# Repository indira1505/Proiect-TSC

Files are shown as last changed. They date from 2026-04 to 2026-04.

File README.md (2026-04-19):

INK TIME SMARTWATCH

1. DIAGRAMA COMPONENTE
    Acesta este un proiect de ceas inteligent bazat pe arhitectura nRF52840, echipat cu un ecran
e-Paper pentru consum redus și un sistem de alertă haptică.

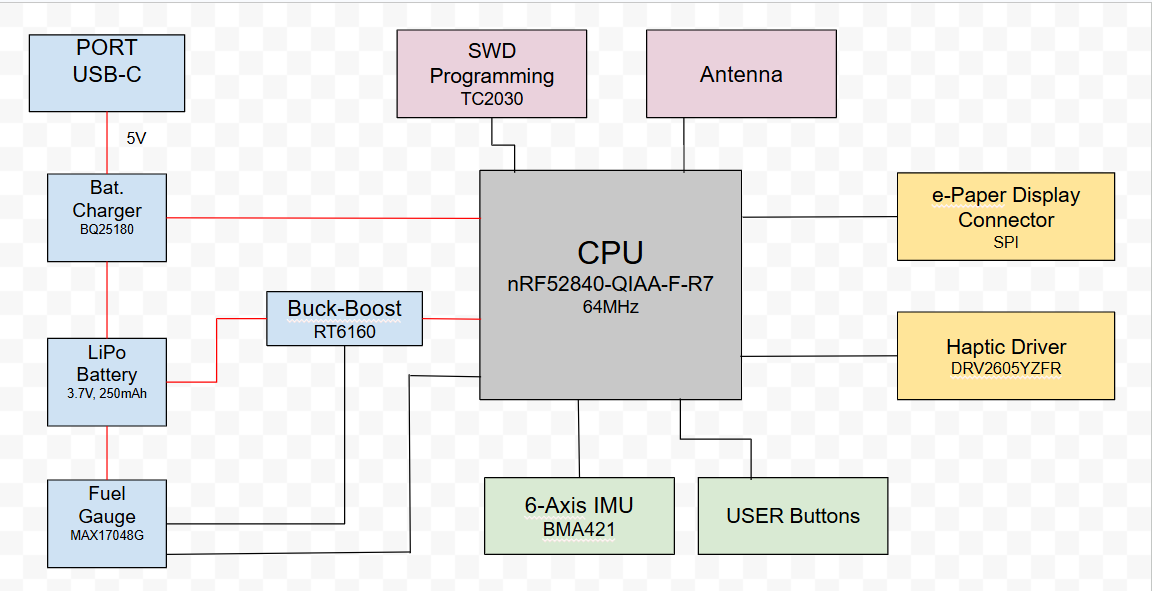
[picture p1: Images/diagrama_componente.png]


2. Bill Of Materials

| Qty | Value | Device | Package | Parts | Description | ARROW_PART_NUMBER | ARROW_PRICE-STOCK | AVAILABILITY | CHECK_PRICES | COPYRIGHT | DESCRIPTION | HEIGHT | JLCPCB | MANUFACTURER_NAME | MANUFACTURER_PART_NUMBER | MF | MFR_NAME | MOUSER_PART_NUMBER | MOUSER_PRICE-STOCK | MP | PACKAGE | POPULARITY | PRICE | PROD_ID | PURCHASE-URL | SNAPEDA_LINK | TP_SIGNAL_NAME | U1 | VALUE |
|-----|---|---|---|---|---|---|---|---|---|---|---|---|---|---|---|---|---|---|---|---|---|---|---|---|---|---|---|---|---|
| 1 | RT6160AWSC | RT6160AWSC_RT6160AWSC | RT6160AWSC_BGA15C40P3X5_140X230X60 | IC9 | Buck-Boost Regulator Positive Output Step-Up/Step-Down I2C DC-DC Controller IC 15-WL-CSP (BSC) (1.4x2.3) | | | | | | Buck-Boost Regulator Positive Output Step-Up/Step-Down I2C DC-DC Controller IC 15-WL-CSP (BSC) (1.4x2.3) | 0.6mm | | RICHTEK | RT6160AWSC | | | 835-RT6160AWSC | https://www.mouser.co.uk/ProductDetail/Richtek/RT6160AWSC?qs=amGC7iS6iy%2FLd9PSoixZXQ%3D%3D | | | | | | | | | | |
| 1 | SI1308EDL-T1-GE3 | ESP32_C6_LIBRARY_6_SI1308EDL-T1-GE3 | ESP32_C6_LIBRARY_6_SOT65P210X110-3N | Q3 | MOSFET N-Ch 30V 1.5A TrenchFET SC70 Vishay Si1308EDL-T1-GE3 N-channel MOSFET Transistor, 1.5 A, 30 V, 3-Pin SC-70 | | | In Stock | https://www.snapeda.com/parts/SI1308EDL-T1-GE3/Vishay+Siliconix/view-part/?ref=eda | | Si1308EDL-T1-GE3 N-channel MOSFET Transistor | 1.5 A | 30 V | 3-Pin SC-70 | Siliconix / Vishay SI1308EDL-T1-GE3 | | | | | Vishay Siliconix | | | | SI1308EDL-T1-GE3 | SOT-323 Vishay Semiconductor | | None | | https://www.snapeda.com/api/url_track_click_mouser/?unipart_id=274603&manufacturer=Vishay Siliconix&part_name=SI1308EDL-T1-GE3&search_term=None | https://www.snapeda.com/parts/SI1308EDL-T1-GE3/Vishay+Siliconix/view-part/?ref=snap |
| 1 | TC2030-IDC | TC2030-IDC_TC2030-IDC | TC2030-IDC_TC2030IDC | J2 | CABLE ADAPTER 6 POS | | | | | | CABLE ADAPTER 6 POS | 19mm | | Tag Connect | TC2030-IDC | | | | | | | | | | | | | | |
| 1 | USBLC6-2SC6Y | ESP32_C6_LIBRARY_3_USBLC6-2SC6Y | ESP32_C6_LIBRARY_3_SOT95P280X145-6N | D3 | Low Cap. ESD Protection Auto SOT-23-6 STMicroelectronics USBLC6-2SC6Y, Dual Uni-Directional TVS Diode Array, 6-Pin SOT-23 | | | In Stock | https://www.snapeda.com/parts/USBLC6-2SC6Y/STMicroelectronics/view-part/?ref=eda | | 17V Clamp 5A (8/20µs) Ipp Tvs Diode Surface Mount SOT-23-6 | | | | | STMicroelectronics | | | | USBLC6-2SC6Y | SOT-23-6 STMicroelectronics | | None | | | https://www.snapeda.com/parts/USBLC6-2SC6Y/STMicroelectronics/view-part/?ref=snap | | | |
| 1 | 0.1uF/50V | NORDIC_NRF_3_CAPACITOR_0201_L | NORDIC_NRF_3_RESC0201_L | EPD_C5 | Generic chip capacitor | | | | | | | | | | | | | | | | | | | | | | | | |
| 1 | 0.47 | CPF0201D7K68C1_CPF0201D7K68C1 | CPF0201D7K68C1_0201 | R1_EP_DR | 7.68k 0201 Thin Film Surface Mount Fixed Resistor +/-0.5% 0.031W CPF0201D7K68C1 | | | | | | | | | | | | | | | | | | | | | | | | |
| 1 | 1.0µF | NORDIC_NRF_3_CAPACITOR_0201_L | NORDIC_NRF_3_RESC0201_L | C15 | Generic chip capacitor | | | | | | | | | | | | | | | | | | | | | | | | |
| 5 | 100nF | NORDIC_NRF_3_CAPACITOR_0201_L | NORDIC_NRF_3_RESC0201_L | C5, C7, C8, C12, C19 | Generic chip capacitor | | | | | | | | | | | | | | | | | | | | | | | | |
| 1 | 100pF | NORDIC_NRF_3_CAPACITOR_0201_L | NORDIC_NRF_3_RESC0201_L | C11 | Generic chip capacitor | | | | | | | | | | | | | | | | | | | | | | | | |
| 4 | 0.1uF | GRM011R60J152KE01L_2_GRM011R60J152KE01L | GRM011R60J152KE01L_2_CAPC0201X13N | C23, C27, C34, C42 | Check availability | | | In Stock | https://www.snapeda.com/parts/GRM011R60J152KE01L/Murata/view-part/?ref=eda | | SMD Capacitor X5R(EIA) with Capacitance: 1500pF Tol. 10%. Rated Voltage: 6.3Vdc | | | | | Murata | | | | GRM011R60J152KE01L | 0201 Murata | | None | | | https://www.snapeda.com/parts/GRM011R60J152KE01L/Murata/view-part/?ref=snap | | | |
| 3 | 10K | CPF0201D7K68C1_CPF0201D7K68C1 | CPF0201D7K68C1_0201 | R2_EP_DR, R9, R_PWR_EPD | 7.68k 0201 Thin Film Surface Mount Fixed Resistor +/-0.5% 0.031W CPF0201D7K68C1 | | | | | | | | | | | | | | | | | | | | | | | | |
| 3 | 10K | ERA-1AEB3401C_CPF0201D7K68C1 | ERA-1AEB3401C_0201 | R5, R7, R8 | 7.68k 0201 Thin Film Surface Mount Fixed Resistor +/-0.5% 0.031W CPF0201D7K68C1 | | | | | | | | | | | | | | | | | | | | | | | | |
| 1 | 10uF | NORDIC_NRF_3_CAPACITOR_0201_L | NORDIC_NRF_3_RESC0201_L | C1-EP-DR | Generic chip capacitor | | | | | | | | | | | | | | | | | | | | | | | | |
| 2 | 10uF | PERFECT_0402_CAP_0402 | PERFECT_0402_0402 | C24, C39 | 0402 (1005 Metric) | | | | | | | | | | | | | | | | | | | | | | | | |
| 1 | | ESP32_C6_LIBRARY_7_JUMPER_SJ | ESP32_C6_LIBRARY_7_JUMPER_SJ | SJ1 | SMD solder JUMPER | | | | | | | | | | | | | | | | | 3 | | | | | | | |
| 3 | 0 | CPF0201D7K68C1_CPF0201D7K68C1 | CPF0201D7K68C1_0201 | R2, R3, R4 | 7.68k 0201 Thin Film Surface Mount Fixed Resistor +/-0.5% 0.031W CPF0201D7K68C1 | | | | | | | | | | | | | | | | | | | | | | | | |
| 1 | 10µH | NORDIC_NRF_2_INDUCTOR_0402_L | NORDIC_NRF_2_RESC0402_L | L2 | Generic chip inductor | | | | | | | | | | | | | | | | | | | | | | | | |
| 4 | 12pF | NORDIC_NRF_3_CAPACITOR_0201_L | NORDIC_NRF_3_RESC0201_L | C1, C2, C17, C18 | Generic chip capacitor | | | | | | | | | | | | | | | | | | | | | | | | |
| 1 | 15nH | NORDIC_NRF_2_INDUCTOR_0402_L | NORDIC_NRF_2_RESC0402_L | L3 | Generic chip inductor | | | | | | | | | | | | | | | | | | | | | | | | |
| 2 | 1pF | NORDIC_NRF_3_CAPACITOR_0201_L | NORDIC_NRF_3_RESC0201_L | C3, C4 | Generic chip capacitor | | | | | | | | | | | | | | | | | | | | | | | | |
| 6 | 1uF | GRM011R60J152KE01L_2_GRM011R60J152KE01L | GRM011R60J152KE01L_2_CAPC0201X13N | C29, C30, C31, C32, C37, C38 | Check availability | | | In Stock | https://www.snapeda.com/parts/GRM011R60J152KE01L/Murata/view-part/?ref=eda | | SMD Capacitor X5R(EIA) with Capacitance: 1500pF Tol. 10%. Rated Voltage: 6.3Vdc | | | | | Murata | | | | GRM011R60J152KE01L | 0201 Murata | | None | | | https://www.snapeda.com/parts/GRM011R60J152KE01L/Murata/view-part/?ref=snap | | | |
| 9 | 1uF/50V | NORDIC_NRF_3_CAPACITOR_0201_L | NORDIC_NRF_3_RESC0201_L | EPD_C1, EPD_C2, EPD_C6, EPD_C7, EPD_C8, EPD_C9, EPD_C10, EPD_C11, EPD_C12 | Generic chip capacitor | | | | | | | | | | | | | | | | | | | | | | | | |
| 1 | 2.2 | CPF0201D7K68C1_CPF0201D7K68C1 | CPF0201D7K68C1_0201 | R_TYPE_SEL | 7.68k 0201 Thin Film Surface Mount Fixed Resistor +/-0.5% 0.031W CPF0201D7K68C1 | | | | | | | | | | | | | | | | | | | | | | | | |
| 3 | 2025-10-22_07-23-44_LIBRARY_EVP-AKE31A | 2025-10-22_07-23-44_LIBRARY_EVP-AKE31A | 2025-10-22_07-23-44_LIBRARY_SW_EVP-AKE31A_PAN | SW_DN, SW_ENT, SW_UP | | | | | | | | | | | | | | | | | | | | | | | | | |
| 1 | 20V/4.2A/52mΩ/1.4W | ESP32_C6_LIBRARY_4_ESP32_WROVER_SPARKFUN-DISCRETESEMI_MOSFET_PCH-DMG2305UX-7 | ESP32_C6_LIBRARY_4_ESP32_C6_LIBRARY_4_ESP32_C6_LIBRARY_4_ESP32_C6_LIBRARY_4_ESP32_WROVER_SPARKFUN-DISCRETESEMI_SOT23-3 | Q1 | P-channel MOSFETs | | | | | | | | | | | | | | | | | | | TRAN-14388 | | | | | 20V/4.2A/52mΩ/1.4W |
| 2 | 22uF | PERFECT_0402_CAP_0402 | PERFECT_0402_0402 | C25, C33 | 0402 (1005 Metric) | | | | | | | | | | | | | | | | | | | | | | | | |
| 1 | 2450AT18B100E | 2450AT18B100E_2450AT18B100E | 2450AT18B100E_ANTC3216X140N | ANT1 | Antennas 2.45GHz ANTENNA | 2450AT18B100E | https://www.arrow.com/en/products/2450at18b100e/johanson-dielectrics?utm_currency=USD&region=nac | | | | Antennas 2.45GHz ANTENNA | 1.4mm | | JOHANSON TECHNOLOGY | 2450AT18B100E | | | 609-2450AT18B100E  | https://www.mouser.co.uk/ProductDetail/Johanson-Technology/2450AT18B100E?qs=yCnrNFeXz%252Bh5MFsFIXGZGA%3D%3D | | | | | | | | | | |
| 1 | 3.9nH | NORDIC_NRF_2_INDUCTOR_0402_L | NORDIC_NRF_2_RESC0402_L | L1 | Generic chip inductor | | | | | | | | | | | | | | | | | | | | | | | | |
| 1 | 32.768kHz | NORDIC_NRF_1_XTAL_32KHZ | NORDIC_NRF_1_XTAL_3215_N | X2 | | | | | | | | | | | | | | | | | | | | | | | | | |
| 1 | 32MHz | NORDIC_NRF_XTAL_32MHZ | NORDIC_NRF_BT-XTAL_2016_N | X1 | | | | | | | | | | | | | | | | | | | | | | | | | |
| 2 | 3K3 | CPF0201D7K68C1_CPF0201D7K68C1 | CPF0201D7K68C1_0201 | R17, R18 | 7.68k 0201 Thin Film Surface Mount Fixed Resistor +/-0.5% 0.031W CPF0201D7K68C1 | | | | | | | | | | | | | | | | | | | | | | | | |
| 1 | 4.7uF | NORDIC_NRF_3_CAPACITOR_0201_L | NORDIC_NRF_3_RESC0201_L | C43 | Generic chip capacitor | | | | | | | | | | | | | | | | | | | | | | | | |
| 1 | 4.7uF/25V | NORDIC_NRF_3_CAPACITOR_0201_L | NORDIC_NRF_3_RESC0201_L | C2-EP-DR | Generic chip capacitor | | | | | | | | | | | | | | | | | | | | | | | | |
| 4 | 4.7µF | NORDIC_NRF_3_CAPACITOR_0201_L | NORDIC_NRF_3_RESC0201_L | C6, C14, C20, C21 | Generic chip capacitor | | | | | | | | | | | | | | | | | | | | | | | | |
| 1 | 47nF | NORDIC_NRF_3_CAPACITOR_0201_L | NORDIC_NRF_3_RESC0201_L | C16 | Generic chip capacitor | | | | | | | | | | | | | | | | | | | | | | | | |
| 1 | 503480-2400 | 503480-2400_503480-2400 | 503480-2400_5034802400 | J1 | FFC & FPC Connectors 0.5mm FPC RA SMT Dual Contact 24Ckt | | | | | | FFC & FPC Connectors 0.5mm FPC RA SMT Dual Contact 24Ckt | 1.87mm | | Molex | 503480-2400 | | | 538-503480-2400 | https://www.mouser.co.uk/ProductDetail/Molex/503480-2400?qs=OAhjpuo3Vu7efIoxFh9AOw%3D%3D | | | | | | | | | | |
| 2 | 5K1 | CPF0201D7K68C1_CPF0201D7K68C1 | CPF0201D7K68C1_0201 | R1_USB, R2_USB | 7.68k 0201 Thin Film Surface Mount Fixed Resistor +/-0.5% 0.031W CPF0201D7K68C1 | | | | | | | | | | | | | | | | | | | | | | | | |
| 1 | 68uH | ESP32_C6_LIBRARY_2_744043680IND_4828-WE-TPC_WRE | ESP32_C6_LIBRARY_2_IND_4828-WE-TPC_WRE | L5 | | | | | | Copyright (C) 2024 Ultra Librarian. All rights reserved. | | | | | 744043680 | | Wurth Electronics | | | | | | | | | | | | |
| 1 | 820pF N.C. | NORDIC_NRF_3_CAPACITOR_0201_L | NORDIC_NRF_3_RESC0201_L | C9 | Generic chip capacitor | | | | | | | | | | | | | | | | | | | | | | | | |
| 1 | BMA421 | BMA423_BMA423 | BMA423_BMA423 | IC3 | Accelerometers Triaxial low-g 12bit Acceleration Sensor | BMA423 | https://www.arrow.com/en/products/bma423/bosch | | | | Accelerometers Triaxial low-g 12bit Acceleration Sensor | 1mm | | BOSCH | BMA423 | | | 262-BMA423 | https://www.mouser.co.uk/ProductDetail/Bosch-Sensortec/BMA423?qs=HXFqYaX1Q2xC%252BSgeGoX3mg%3D%3D | | | | | | | | | | |
| 1 | BQ25180YBGR | BQ25180YBGR_BQ25180YBGR | BQ25180YBGR_BGA8C40P2X4_100X155X50 | IC1 | Charger IC Lithium Ion/Polymer, Lithium Iron Phosphate 8-DSBGA (1.6x1.1) | BQ25180YBGR | https://www.arrow.com/en/products/bq25180ybgr/texas-instruments?utm_currency=USD&region=nac | | | | Charger IC Lithium Ion/Polymer | Lithium Iron Phosphate 8-DSBGA (1.6x1.1) | 0.5mm | | Texas Instruments | BQ25180YBGR | | | 595-BQ25180YBGR | https://www.mouser.co.uk/ProductDetail/Texas-Instruments/BQ25180YBGR?qs=doiCPypUmgEWjAK%252BJAX6Tw%3D%3D | | | | | | | | | |
| 1 | DRV2605YZFR | DRV2605YZFR_DRV2605YZFR | DRV2605YZFR_BGA9C50P3X3_144X144X62 | IC2 | Haptic Driver for ERM/LRA with Built-In Library and Smart Loop Architecture | DRV2605YZFR | https://www.arrow.com/en/products/drv2605yzfr/texas-instruments?region=nac | | | | Haptic Driver for ERM/LRA with Built-In Library and Smart Loop Architecture | 0.625mm | | Texas Instruments | DRV2605YZFR | | | | | | | | | | | | | | |
| 1 | FTC252012SR47MBCA | MLP2016SR47MT0S1_FTC252012SR47MBCA | MLP2016SR47MT0S1_INDC2016X100N | L7 | SMD / SMT Inductors (Coils), L=0.47?H, L x W x T : | | | | | | SMD / SMT Inductors (Coils) | L=0.47?H | L x W x T : | 1mm | https://jlcpcb.com/partdetail/6763488-FTC252012SR47MBCA/C5832368 | TDK | FTC252012SR47MBCA | | | | | | | | | | | | |
| 14  | HECTOR_WATCH_1_TPTP20R | HECTOR_WATCH_1_TPTP20R | HECTOR_WATCH_1_TP20R | TP_3.3V, TP_3V3, TP_BAT_GND, TP_GND, TP_ON, TP_OP, TP_RESET, TP_SCL, TP_SDA, TP_SWDCLK, TP_SWDIO, TP_SWO, TP_VBAT, TP_VREG | Test pad | | | | | | | | | | | | | | | | | 2 | | | | | | | |
| 1 | KH-TYPE-C-16P | KH-TYPE-C-16P_KH-TYPE-C-16P | KH-TYPE-C-16P_KINGHELM_KH-TYPE-C-16P | J4 | Check availability | | | Not in stock | https://www.snapeda.com/parts/KH-TYPE-C-16P/Kinghelm/view-part/?ref=eda | | | | | | | kinghelm | | | | KH-TYPE-C-16P | None | | None | | | https://www.snapeda.com/parts/KH-TYPE-C-16P/Kinghelm/view-part/?ref=snap | | | |
| 1 | MAX17048G+T10 | ESP32_C6_LIBRARY_MAX17048G+T10 | ESP32_C6_LIBRARY_SON50P200X200X80-9N | U2 | Check availability | | | In Stock | https://www.snapeda.com/parts/MAX17048G+T10/Analog+Devices/view-part/?ref=eda | | 3µA 1-Cell/2-Cell Fuel Gauge with ModelGauge | | | | | Analog Devices | | | | MAX17048G+T10 | TDFN-8 Maxim | | None | | https://www.snapeda.com/api/url_track_click_mouser/?unipart_id=329239&manufacturer=Analog Devices&part_name=MAX17048G+T10&search_term=None | https://www.snapeda.com/parts/MAX17048G+T10/Analog+Devices/view-part/?ref=snap | | | |
| 3 | MBR0530 | ESP32_C6_LIBRARY_5_MBR0530 | ESP32_C6_LIBRARY_5_SOD3716X135N | D2, D4, D5 | ON SEMICONDUCTOR - MBR0530 - DIODE, SCHOTTKY, 0.5A, 30V, SOD-123 | | | In Stock | https://www.snapeda.com/parts/MBR0530/Onsemi/view-part/?ref=eda | | Diode Schottky 30 V 500mA Surface Mount SOD-123 | | | | | ON Semiconductor | | | | MBR0530 | SOD-123-2 ON Semiconductor  | | None | | https://www.snapeda.com/api/url_track_click_mouser/?unipart_id=179458&manufacturer=ON Semiconductor&part_name=MBR0530&search_term=None | https://www.snapeda.com/parts/MBR0530/Onsemi/view-part/?ref=snap | | | |
| 3 | N.C. | NORDIC_NRF_3_CAPACITOR_0201_L | NORDIC_NRF_3_RESC0201_L | C10, C13, C22 | Generic chip capacitor | | | | | | | | | | | | | | | | | | | | | | | | |
| 1 | NRF52840 _QF | NORDIC_NRF_4_NRF52840_QF | NORDIC_NRF_4_AQFN50P700X700X85_HS-74N | U1 | nRF52840 | | | | | | | | | | | | | | | | | | | | | | | NRF52840 _QF | |

3. DESCRIEREA FUNCTIONALITATII HARDWARE

Sistemul este construit in jurul SoC-ului nRF52840, fiind optimizat pentru un consum ultra-scazut de energie si securitate hardware.

Module si Componente Cheie:
Microcontroller (nRF52840): Procesor ARM Cortex-M4F cu unitate de criptare hardware CryptoCell-310. Acesta gestioneaza stack-ul Bluetooth Low Energy (BLE) si coordoneaza toate perifericele.

Sistemul de Putere (Power Tree):

BQ25180: IC de incarcare cu Power Path. Permite incarcarea bateriei LiPo si alimentarea simultana a sistemului.

MAX17048: Fuel Gauge (indicator nivel baterie). Masoara precis starea de incarcare (SoC) si tensiunea bateriei, comunicand prin I2C.

RT6160: Regulator Buck-Boost care asigura o tensiune stabila de 3.3V indiferent de nivelul de descarcare al bateriei.

Senzor de Miscare (BMA421): Accelerometru triaxial de mica putere. Este folosit pentru pedometru (numararea pasilor) si detectarea gesturilor (ex: "tilt-to-wake").

Afisaj e-Paper (1.54"): Display de tip "Electronic Ink" care consuma curent doar la refresh. Include un circuit de protectie cu un PFET (SI2301CDS) pentru a opri complet alimentarea ecranului in standby, eliminand scurgerile de curent.

Driver Haptic (DRV2605L): Controleaza motorul de vibratii (Shaker) folosind librarii de efecte pre-programate pentru un feedback tactil premium.

Cristal 32 MHz (X1): Esențial pentru funcționarea blocului radio (Bluetooth). Acesta oferă referința de înaltă frecvență necesară pentru stabilitatea semnalului și procesarea rapidă a datelor.

Cristal 32.768 kHz (X2): Componentă critică pentru optimizarea consumului. Acesta permite funcționarea ceasului de timp real (RTC) în modurile de Deep Sleep, menținând precizia timpului cu un consum infim de energie, fără a fi nevoie de oscilatorul intern RC (care este mai puțin precis și consumă mai mult).

Antena: Sistemul utilizează o antenă de tip traseu pe cablaj (Trace Antenna), calculată pentru frecvența de 2.4 GHz (Bluetooth Low Energy).Pentru a asigura o rază de acțiune maximă, s-a respectat o zonă de "Keep-out" (fără cupru) pe toate straturile sub antenă, prevenind astfel atenuarea semnalului.

Interfete de Comunicatie:
I2C (SDA/SCL): Magistrala principala de senzori unde sunt conectate: BMA421, DRV2605L, BQ25180 si MAX17048.

SPI: Interfata de mare viteza folosita exclusiv pentru ecranul e-Paper.

PWM: Folosit pentru controlul intensitatii vibratiilor shaker-ului.

Procesare si Energie:
Procesare: Cipul ruleaza la 64MHz, dar sta majoritatea timpului in System ON Sleep mode (~3uA).

Consum: Bateria de 250mAh sustine o autonomie estimata de 30-45 zile, avand in vedere ca ecranul nu consuma energie intre update-uri si senzorii sunt configurati pe modul de consum minim cu intreruperi.

4. Configuratia Pinilor nRF52840

| Componenta | Pin nRF52 | Functie | Motivatie Tehnica |
|---|---|---|---|
| I2C SCL | P0.27 | Clock | Pin dedicat pentru magistrala de senzori (I2C). |
| I2C SDA | P0.26 | Data | Linie de date partajata intre BMA421, Gauge si Charger.  |
| EPD SCK | P0.28 | SPI Clock | Pin de mare viteza pentru refresh-ul ecranului. |
| EPD MOSI | P0.29 | SPI Data | Transferul buffer-ului de imagine catre display. |
| EPD CS | P0.30 | Chip Select | Activarea comunicatiei cu ecranul. |
| EPD DC | P0.31 | Data/Cmd | Pin necesar pentru protocolul e-Paper (comenzi vs date). |
| EPD BUSY | P0.04 | Input | Monitorizeaza cand ecranul a terminat actualizarea. |
| Shaker | P0.02 | PWM/EN | Pin capabil de PWM pentru controlul driverului haptic. |
| Buton UP | P1.00 | GPIO | Pin cu intrerupere pentru navigare meniu (sus). |
| Buton DN | P1.01 | GPIO | Pin cu intrerupere pentru navigare meniu (jos). |
| Buton ENT  | P1.02 | GPIO | Pin cu intrerupere pentru selectie/confirmare. |
| LED 1/2 | P0.13, P0.14 | Output | LED-uri de stare pentru notificari vizuale rapide. 

IMAGINI

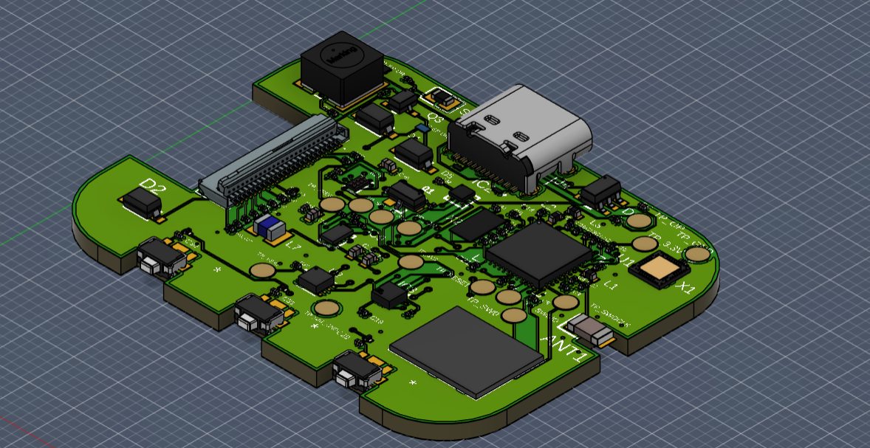
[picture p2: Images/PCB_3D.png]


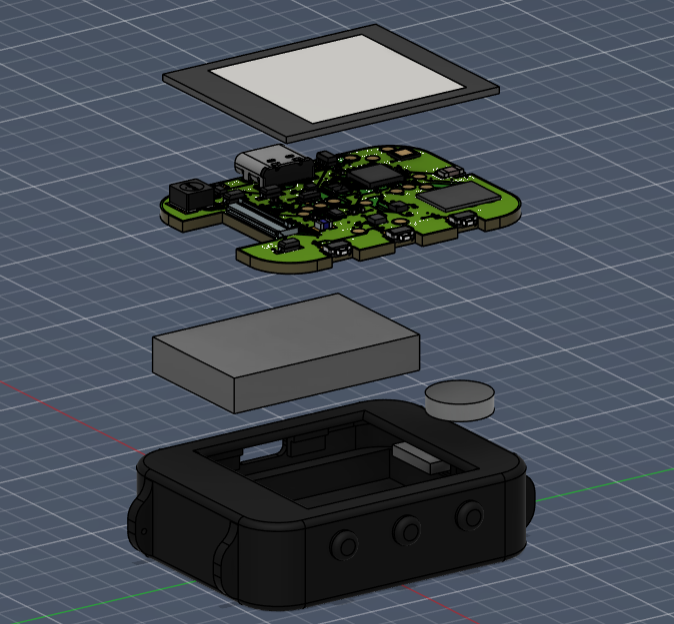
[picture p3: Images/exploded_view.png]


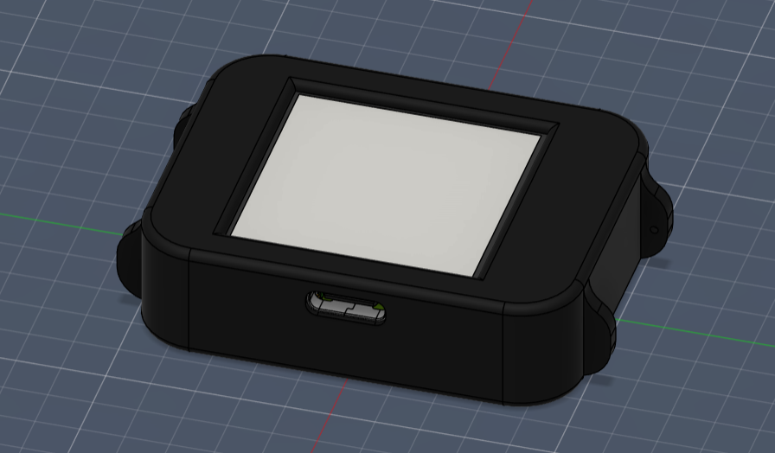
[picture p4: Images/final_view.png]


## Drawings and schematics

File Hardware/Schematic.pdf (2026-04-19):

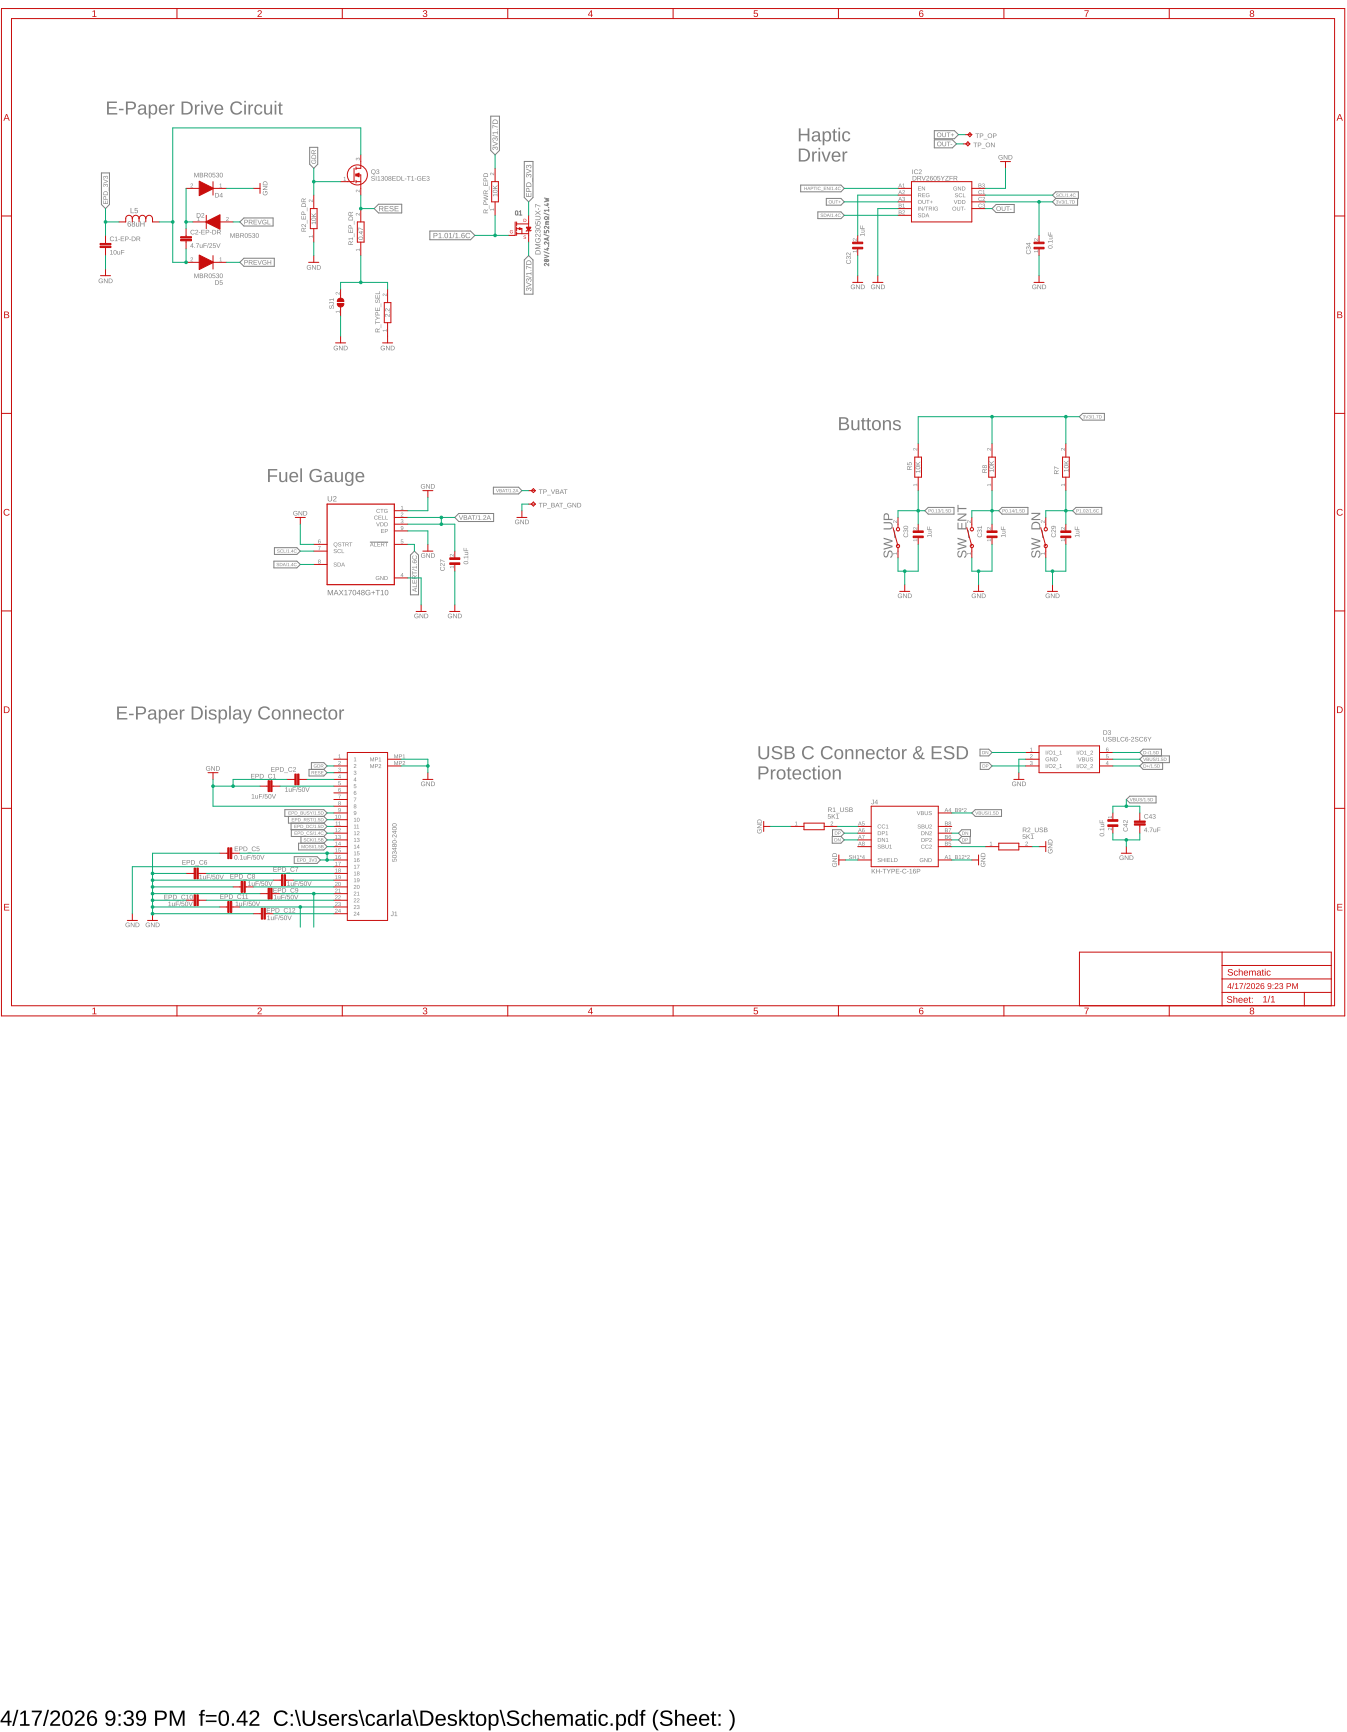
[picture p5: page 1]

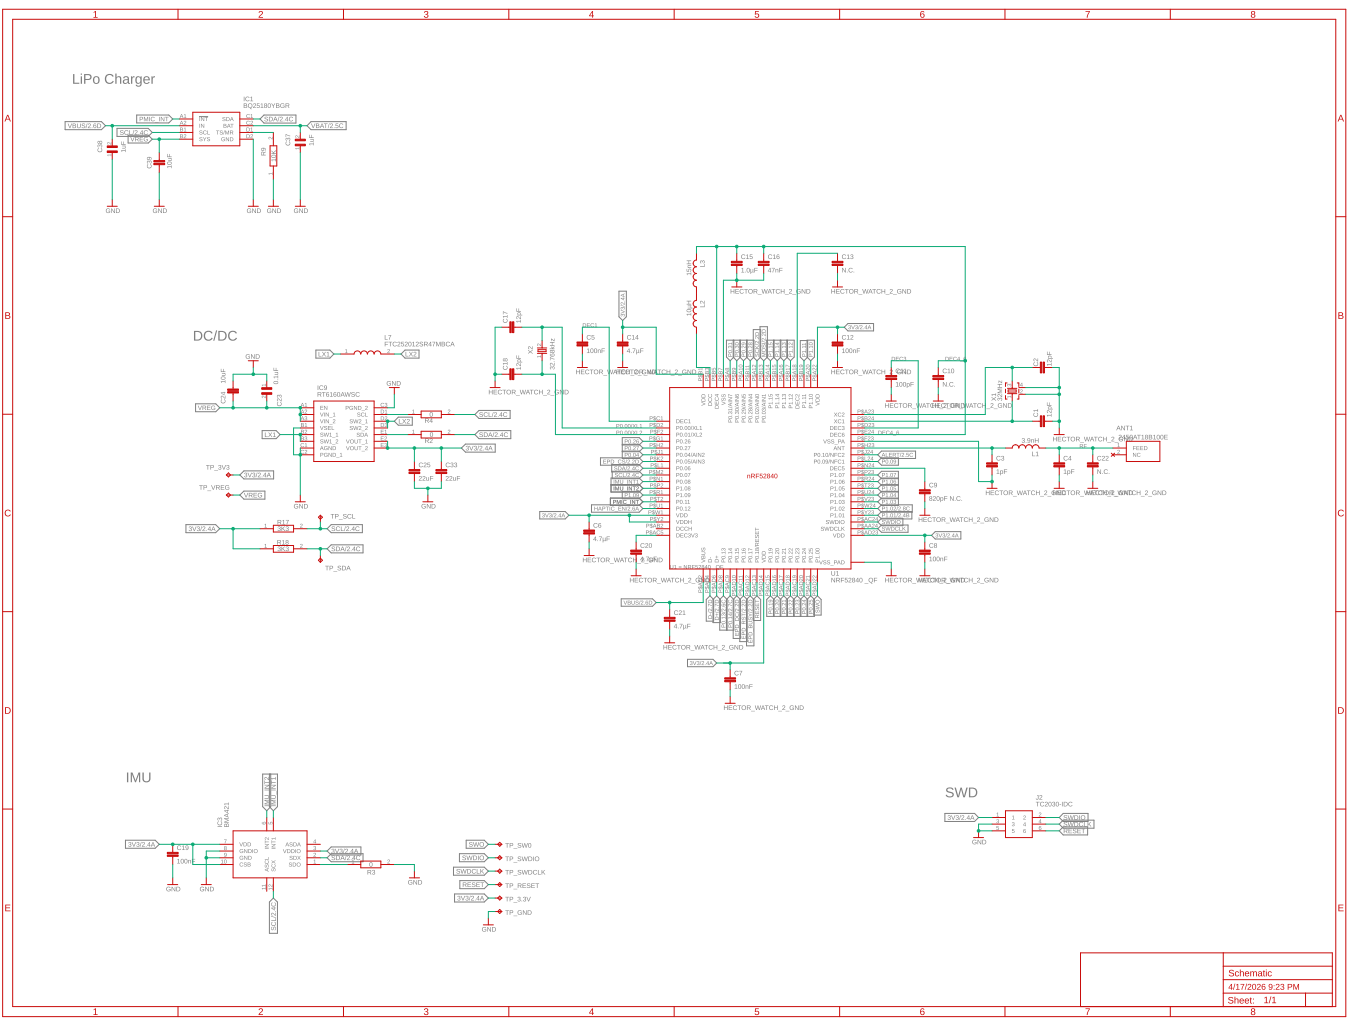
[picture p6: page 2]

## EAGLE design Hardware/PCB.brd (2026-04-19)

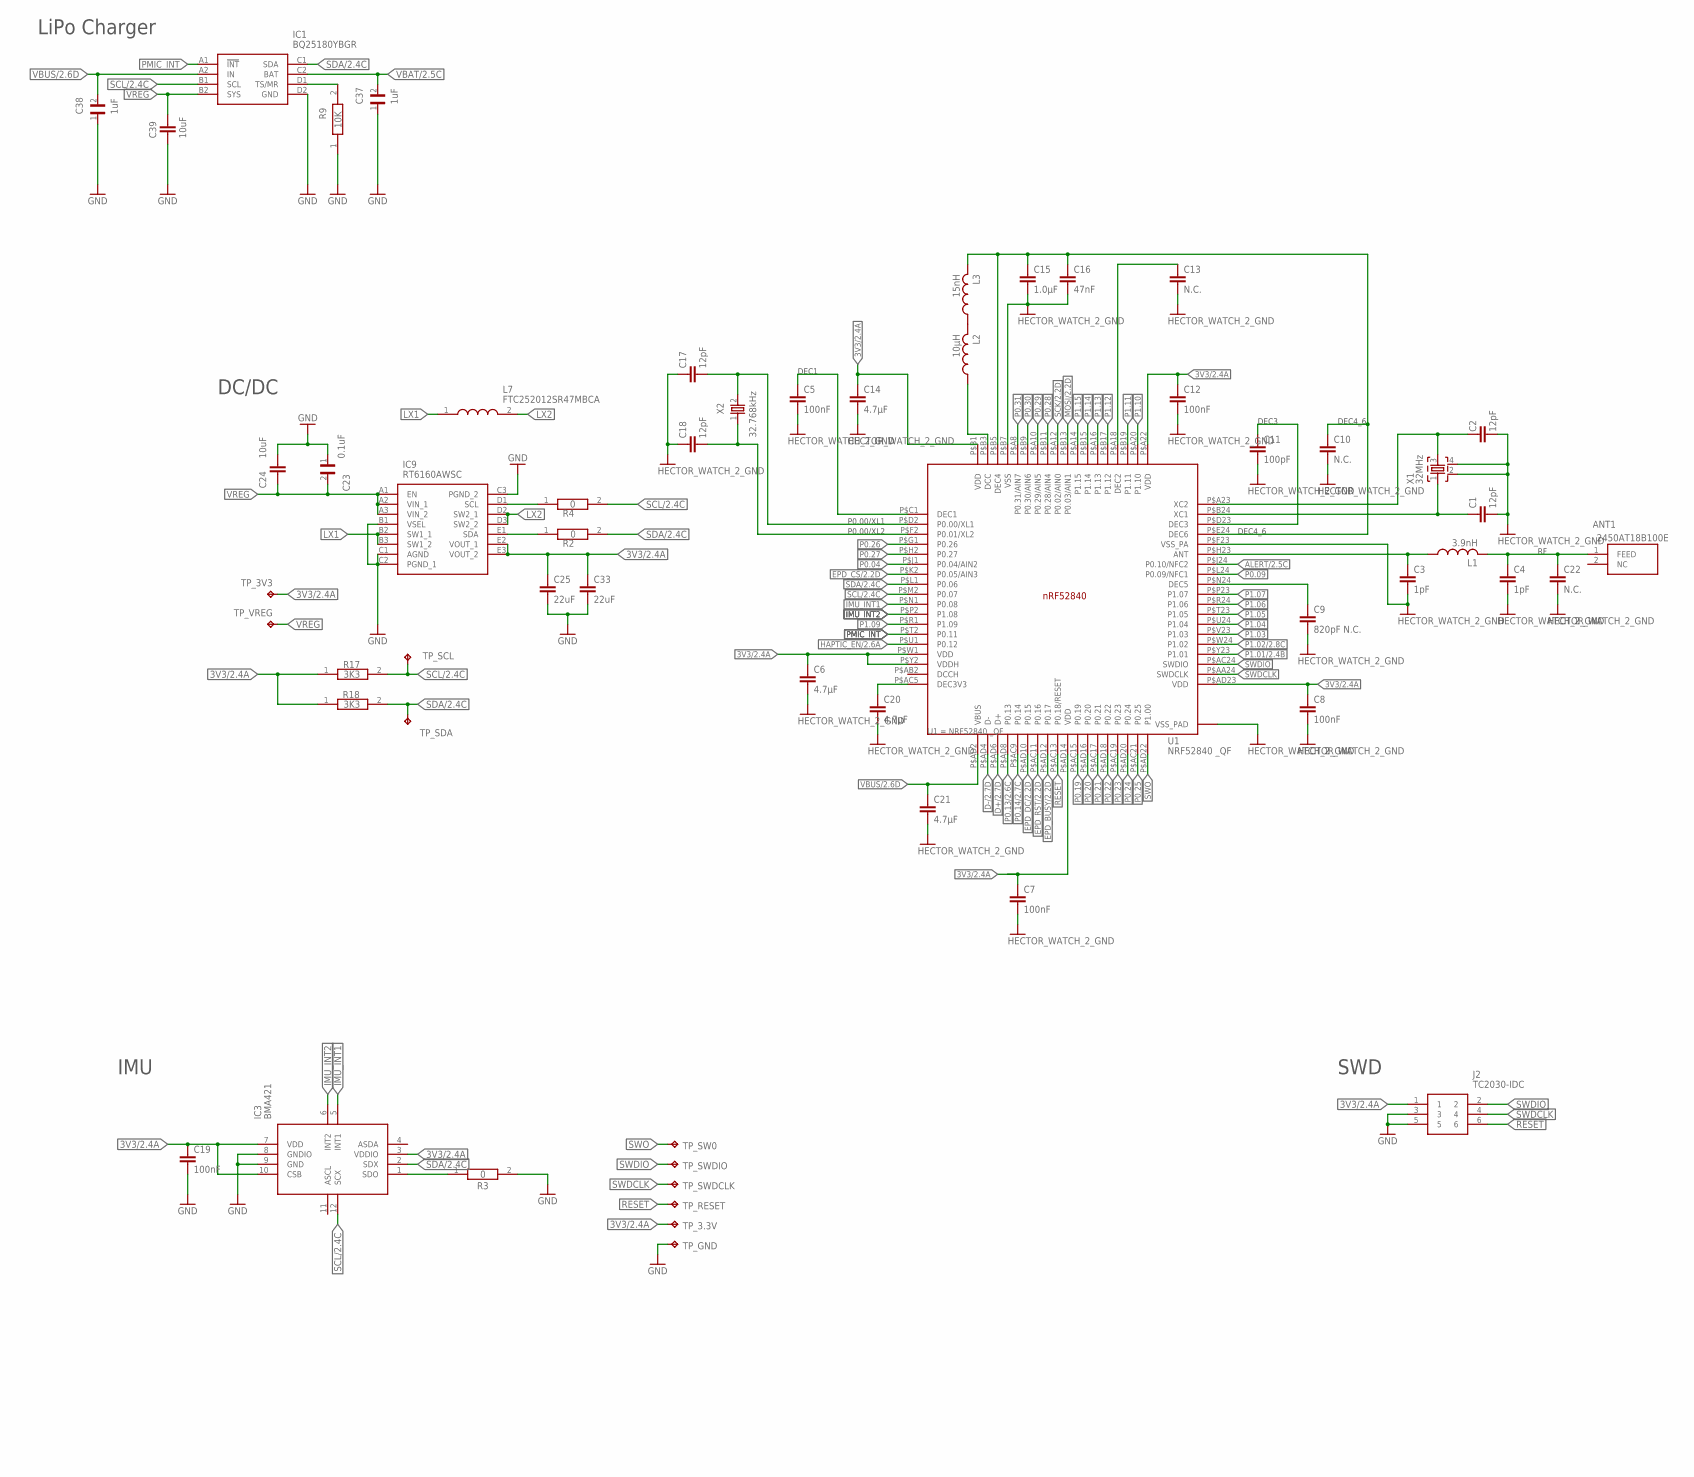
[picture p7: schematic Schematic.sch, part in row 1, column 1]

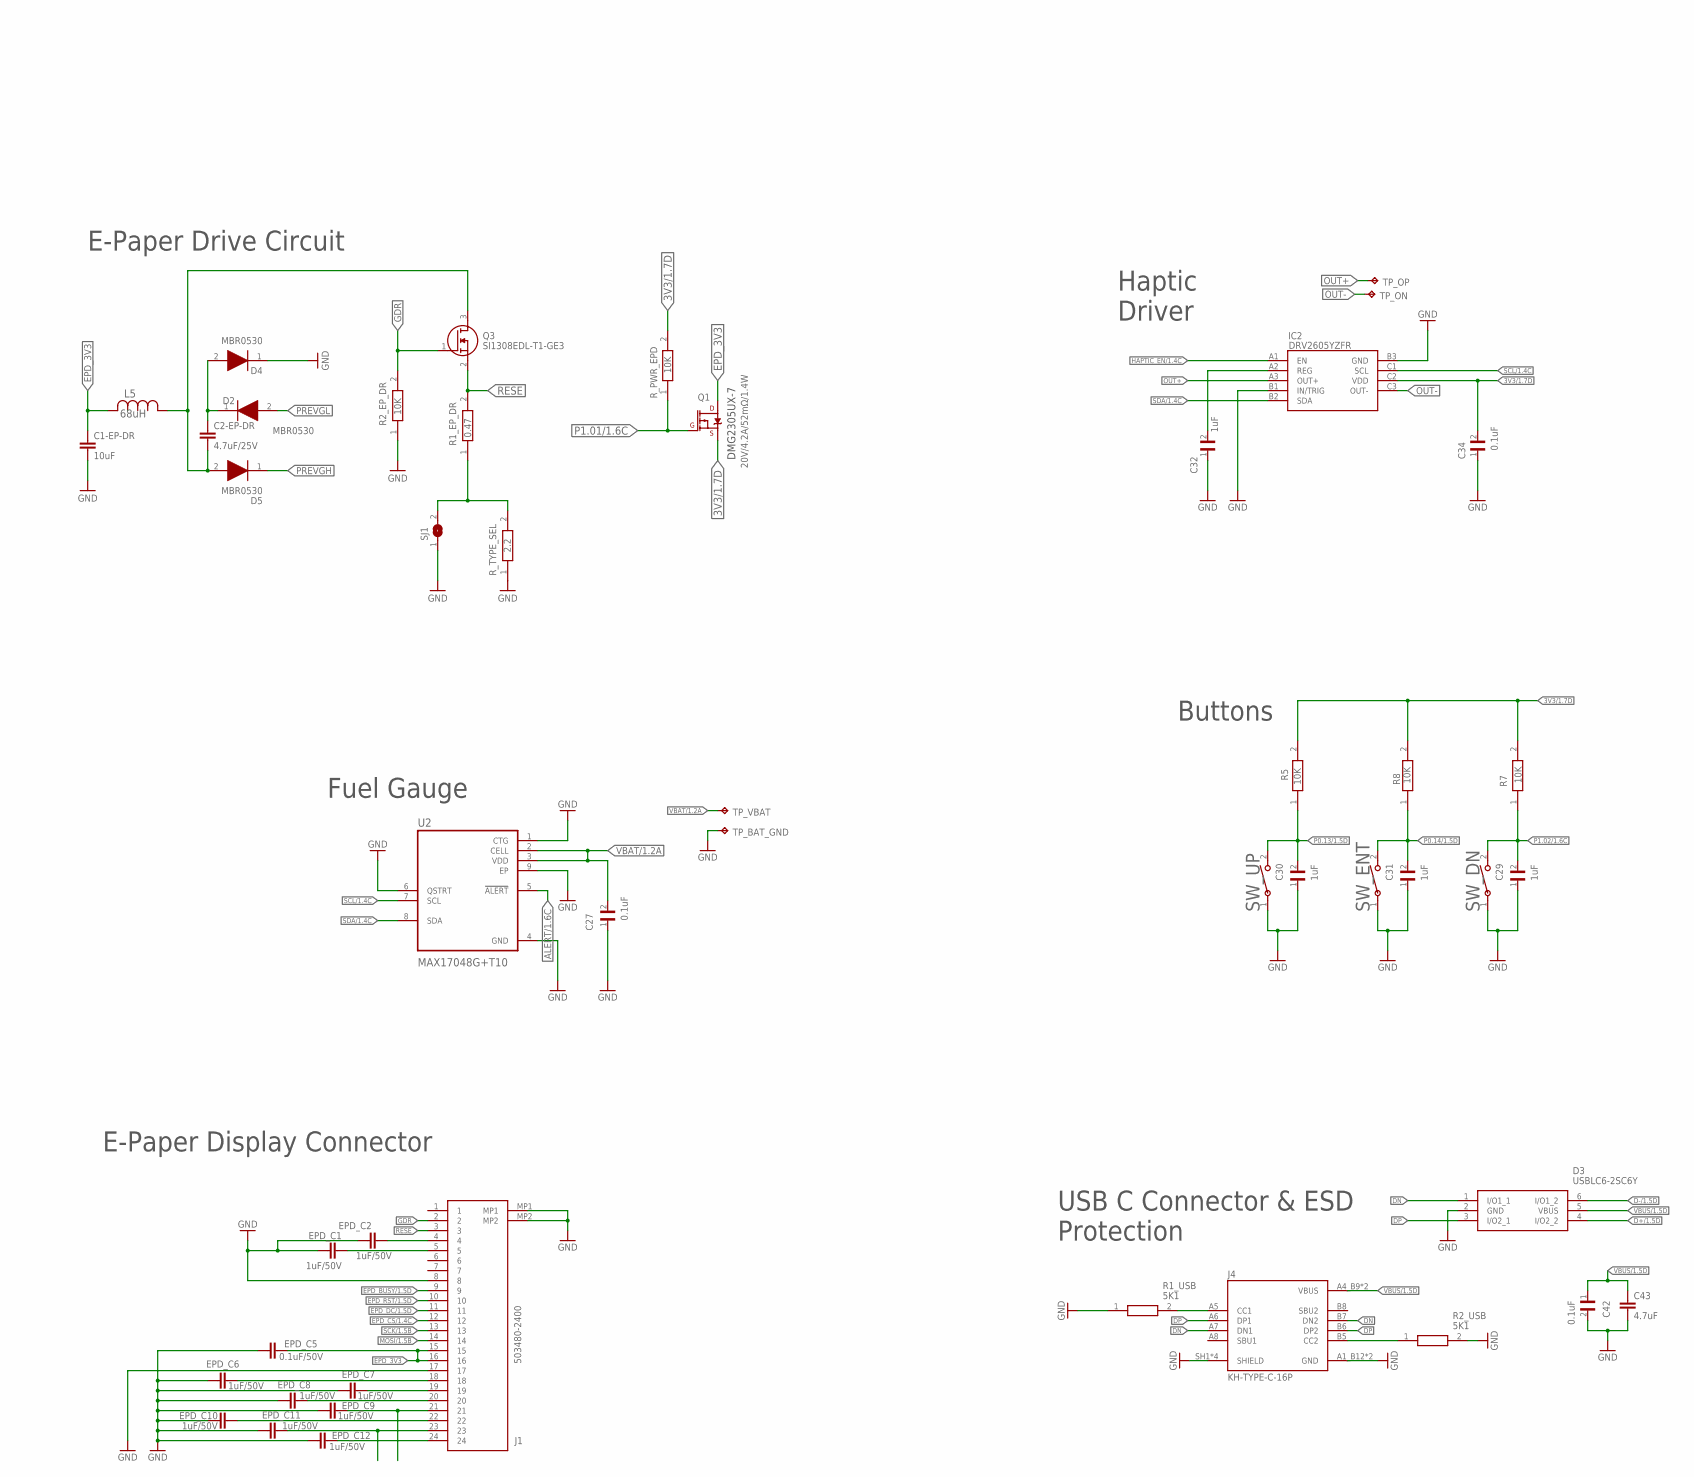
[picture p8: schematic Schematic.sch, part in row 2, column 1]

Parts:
ANT1: 2450AT18B100E; 2450AT18B100E_ANTC3216X140N
C1, C2, C17, C18: 12pF; NORDIC_NRF_3_RESC0201_L
C1-EP-DR: 10uF; NORDIC_NRF_3_RESC0201_L
C2-EP-DR: 4.7uF/25V; NORDIC_NRF_3_RESC0201_L
C3, C4: 1pF; NORDIC_NRF_3_RESC0201_L
C5, C7, C8, C12, C19: 100nF; NORDIC_NRF_3_RESC0201_L
C6, C14, C20, C21: 4.7µF; NORDIC_NRF_3_RESC0201_L
C9: 820pF N.C.; NORDIC_NRF_3_RESC0201_L
C10, C13, C22: N.C.; NORDIC_NRF_3_RESC0201_L
C11: 100pF; NORDIC_NRF_3_RESC0201_L
C15: 1.0µF; NORDIC_NRF_3_RESC0201_L
C16: 47nF; NORDIC_NRF_3_RESC0201_L
C23, C27, C34, C42: 0.1uF; GRM011R60J152KE01L_2_CAPC0201X13N
C24, C39: 10uF; PERFECT_0402_0402
C25, C33: 22uF; PERFECT_0402_0402
C29, C30, C31, C32, C37, C38: 1uF; GRM011R60J152KE01L_2_CAPC0201X13N
C43: 4.7uF; NORDIC_NRF_3_RESC0201_L
D2, D4, D5: MBR0530; ESP32_C6_LIBRARY_5_SOD3716X135N
D3: USBLC6-2SC6Y; ESP32_C6_LIBRARY_3_SOT95P280X145-6N
EPD_C1, EPD_C2, EPD_C6, EPD_C7, EPD_C8, EPD_C9, EPD_C10, EPD_C11, EPD_C12: 1uF/50V; NORDIC_NRF_3_RESC0201_L
EPD_C5: 0.1uF/50V; NORDIC_NRF_3_RESC0201_L
IC1: BQ25180YBGR; BQ25180YBGR_BGA8C40P2X4_100X155X50
IC2: DRV2605YZFR; DRV2605YZFR_BGA9C50P3X3_144X144X62
IC3: BMA421; BMA423_BMA423
IC9: RT6160AWSC; RT6160AWSC_BGA15C40P3X5_140X230X60
J1: 503480-2400; 503480-2400_5034802400
J2: TC2030-IDC; TC2030-IDC_TC2030IDC
J4: KH-TYPE-C-16P; KH-TYPE-C-16P_KINGHELM_KH-TYPE-C-16P
L1: 3.9nH; NORDIC_NRF_2_RESC0402_L
L2: 10µH; NORDIC_NRF_2_RESC0402_L
L3: 15nH; NORDIC_NRF_2_RESC0402_L
L5: 68uH; ESP32_C6_LIBRARY_2_IND_4828-WE-TPC_WRE
L7: FTC252012SR47MBCA; MLP2016SR47MT0S1_INDC2016X100N
Q1: 20V/4.2A/52mΩ/1.4W; ESP32_C6_LIBRARY_4_ESP32_C6_LIBRARY_4_ESP32_C6_LIBRARY_4_ES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
Q3: SI1308EDL-T1-GE3; ESP32_C6_LIBRARY_6_SOT65P210X110-3N
R1_EP_DR: 0.47; CPF0201D7K68C1_0201
R1_USB, R2_USB: 5K1; ERA-1AEB3401C_0201
R2, R3, R4: 0; CPF0201D7K68C1_0201
R2_EP_DR, R9: 10K; CPF0201D7K68C1_0201
R5, R7, R8: 10K; ERA-1AEB3401C_0201
R17, R18: 3K3; CPF0201D7K68C1_0201
R_PWR_EPD: 10K; CPF0201D7K68C1_0201
R_TYPE_SEL: 2.2; CPF0201D7K68C1_0201
SJ1: ESP32_C6_LIBRARY_7_JUMPER_SJ
SW_DN: 2025-10-22_07-23-44_LIBRARY_EVP-AKE31ASW_EVP-AKE3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; 2025-10-22_07-23-44_LIBRARY_SW_EVP-AKE31A_PAN
SW_ENT: 2025-10-22_07-23-44_LIBRARY_EVP-AKE31ASW_EVP-AKE3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; 2025-10-22_07-23-44_LIBRARY_SW_EVP-AKE31A_PAN
SW_UP: 2025-10-22_07-23-44_LIBRARY_EVP-AKE31ASW_EVP-AKE3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; 2025-10-22_07-23-44_LIBRARY_SW_EVP-AKE31A_PAN
TP_3.3V, TP_3V3: HECTOR_WATCH_1_TPTP20R; HECTOR_WATCH_1_TP20R
TP_BAT_GND: HECTOR_WATCH_1_TPTP20R; HECTOR_WATCH_1_TP20R
TP_GND: HECTOR_WATCH_1_TPTP20R; HECTOR_WATCH_1_TP20R
TP_ON: HECTOR_WATCH_1_TPTP20R; HECTOR_WATCH_1_TP20R
TP_OP: HECTOR_WATCH_1_TPTP20R; HECTOR_WATCH_1_TP20R
TP_RESET: HECTOR_WATCH_1_TPTP20R; HECTOR_WATCH_1_TP20R
TP_SCL: HECTOR_WATCH_1_TPTP20R; HECTOR_WATCH_1_TP20R
TP_SDA: HECTOR_WATCH_1_TPTP20R; HECTOR_WATCH_1_TP20R
TP_SW0: HECTOR_WATCH_1_TPTP20R; HECTOR_WATCH_1_TP20R
TP_SWDCLK: HECTOR_WATCH_1_TPTP20R; HECTOR_WATCH_1_TP20R
TP_SWDIO: HECTOR_WATCH_1_TPTP20R; HECTOR_WATCH_1_TP20R
TP_VBAT: HECTOR_WATCH_1_TPTP20R; HECTOR_WATCH_1_TP20R
TP_VREG: HECTOR_WATCH_1_TPTP20R; HECTOR_WATCH_1_TP20R
U1: NRF52840 _QF; NORDIC_NRF_4_AQFN50P700X700X85_HS-74N
U2: MAX17048G+T10; ESP32_C6_LIBRARY_SON50P200X200X80-9N
X1: 32MHz; NORDIC_NRF_BT-XTAL_2016_N
X2: 32.768kHz; NORDIC_NRF_1_XTAL_3215_N

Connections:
3V3/1.7D: C34.2, IC2.C2 (VDD), Q1.2 (S), R5.2, R7.2, R8.2, R_PWR_EPD.2
3V3/2.4A: C6.1, C7.1, C8.1, C12.1, C14.1, C19.1, C25.1, C33.1, IC3.3 (VDDIO), IC3.7 (VDD), IC3.10 (CSB), IC9.E2 (VOUT_1), IC9.E3 (VOUT_2), J2.1, R17.1, R18.1, TP_3.3V.TP, TP_3V3.TP, U1.P$A22 (VDD), U1.P$AD14 (VDD), U1.P$AD23 (VDD), U1.P$B1 (VDD), U1.P$W1 (VDD), U1.P$Y2 (VDDH)
ALERT/1.6C: U2.5 (!ALERT)
ALERT/2.5C: U1.P$J24 (P0.10/NFC2)
D+/1.5D: D3.4 (I/O2_2)
D+/2.7D: U1.P$AD6 (D+)
D-/1.5D: D3.6 (I/O1_2)
D-/2.7D: U1.P$AD4 (D-)
DN: D3.1 (I/O1_1), J4.A7 (DN1), J4.B7 (DN2)
DP: D3.3 (I/O2_1), J4.A6 (DP1), J4.B6 (DP2)
EPD_3V3: C1-EP-DR.1, EPD_C5.2, J1.15, J1.16, L5.2, Q1.3 (D)
EPD_BUSY/1.5D: J1.9
EPD_BUSY/2.2D: U1.P$AD12 (P0.17)
EPD_CS/1.4C: J1.12
EPD_CS/2.2D: U1.P$K2 (P0.05/AIN3)
EPD_DC/1.5D: J1.11
EPD_DC/2.2D: U1.P$AD10 (P0.15)
EPD_RST/1.5D: J1.10
EPD_RST/2.2D: U1.P$AC11 (P0.16)
GDR: J1.2, Q3.1 (G), R2_EP_DR.2
GND: C1.2, C1-EP-DR.2, C2.1, C3.2, C4.2, C5.2, C6.2, C7.2, C8.2, C9.2, C10.2, C11.2, C12.2, C13.2, C14.2, C15.2, C16.2, C17.1, C18.1, C19.2, C20.2, C21.2, C22.2, C23.1, C24.1, C25.2, C27.1, C29.1, C30.1, C31.1, C32.1, C33.2, C34.1, C37.1, C38.1, C39.2, C42.2, C43.2, D3.2 (GND), D4.1 (K), EPD_C1.1, EPD_C2.1, EPD_C5.1, EPD_C6.1, EPD_C7.1, EPD_C8.1, EPD_C9.1, EPD_C10.1, EPD_C11.1, EPD_C12.1, IC1.D2 (GND), IC2.B1 (IN/TRIG), IC2.B3 (GND), IC3.8 (GNDIO), IC3.9 (GND), IC9.B1 (VSEL), IC9.C1 (AGND), IC9.C2 (PGND_1), IC9.C3 (PGND_2), J1.8, J1.17, J1.MP1, J1.MP2, J2.3, J2.5, J4.A1_B12 (GND), J4.A12_B1 (GND), J4.SH1 (SHIELD), J4.SH2 (SHIELD), J4.SH3 (SHIELD), J4.SH4 (SHIELD), R1_USB.1, R2_EP_DR.1, R2_USB.2, R3.2, R9.1, R_TYPE_SEL.1, SJ1.1, SW_DN.1, SW_ENT.1, SW_UP.1, TP_BAT_GND.TP, TP_GND.TP, U1.P$74 (VSS_PAD), U1.P$75 (VSS_PAD), U1.P$76 (VSS_PAD), U1.P$77 (VSS_PAD), U1.P$78 (VSS_PAD), U1.P$79 (VSS_PAD), U1.P$80 (VSS_PAD), U1.P$81 (VSS_PAD), U1.P$82 (VSS_PAD), U1.P$83 (VSS_PAD), U1.P$84 (VSS_PAD), U1.P$85 (VSS_PAD), U1.P$86 (VSS_PAD), U1.P$87 (VSS_PAD), U1.P$88 (VSS_PAD), U1.P$89 (VSS_PAD), U1.P$90 (VSS_PAD), U1.P$B7 (VSS), U1.P$F23 (VSS_PA), U2.1 (CTG), U2.4 (GND), U2.6 (QSTRT), U2.9 (EP), X1.2, X1.4
HAPTIC_EN/1.4C: IC2.A1 (EN)
HAPTIC_EN/2.6A: U1.P$U1 (P0.12)
IMU_INT1: IC3.5 (INT1), U1.P$N1 (P0.08)
IMU_INT2: IC3.6 (INT2), U1.P$P2 (P1.08)
LX1: IC9.B2 (SW1_1), IC9.B3 (SW1_2), L7.1
LX2: L7.2
MOSI/1.5B: J1.14
MOSI/2.2D: U1.P$B13 (P0.03/AIN1)
unnamed: IC1.D1 (TS/MR), R9.2
unnamed: L2.1, U1.P$B3 (DCC)
unnamed: IC3.1 (SDO), R3.1
unnamed: L2.2, L3.1
unnamed: C10.1, C15.1, C16.1, L3.2, U1.P$B5 (DEC4), U1.P$E24 (DEC6)
unnamed: C13.1, U1.P$A18 (DEC2)
unnamed: C5.1, U1.P$C1 (DEC1)
unnamed: IC9.E1 (SDA), R2.1
unnamed: C17.2, U1.P$D2 (P0.00/XL1), X2.2
unnamed: IC9.D2 (SW2_1), IC9.D3 (SW2_2)
unnamed: IC9.D1 (SCL), R4.1
unnamed: C18.2, U1.P$F2 (P0.01/XL2), X2.1
unnamed: C20.1, U1.P$AC5 (DEC3V3)
unnamed: C9.1, U1.P$N24 (DEC5)
unnamed: C3.1, L1.1, U1.P$H23 (ANT)
unnamed: ANT1.1 (FEED), C4.1, C22.1, L1.2
unnamed: C11.1, U1.P$D23 (DEC3)
unnamed: C1.1, U1.P$B24 (XC1), X1.1
unnamed: C2.2, U1.P$A23 (XC2), X1.3
unnamed: C2-EP-DR.1, D2.1 (K), D4.2 (A)
unnamed: C2-EP-DR.2, D5.2 (A), L5.1, Q3.3 (D)
unnamed: R1_EP_DR.1, R_TYPE_SEL.2, SJ1.2
unnamed: C32.2, IC2.A2 (REG)
unnamed: J4.A5 (CC1), R1_USB.2
unnamed: J4.B5 (CC2), R2_USB.1
unnamed: EPD_C2.2, J1.4
unnamed: EPD_C1.2, J1.5
unnamed: EPD_C6.2, J1.18
unnamed: EPD_C7.2, J1.19
unnamed: EPD_C8.2, J1.20
unnamed: EPD_C10.2, J1.22
unnamed: EPD_C12.2, J1.24
OUT+: IC2.A3 (OUT+), TP_OP.TP
OUT-: IC2.C3 (OUT-), TP_ON.TP
P0.04: U1.P$J1 (P0.04/AIN2)
P0.09: U1.P$L24 (P0.09/NFC1)
P0.13/1.5D: C30.2, R5.1, SW_UP.2
P0.13/2.6C: U1.P$AD8 (P0.13)
P0.14/1.5D: C31.2, R8.1, SW_ENT.2
P0.14/2.7C: U1.P$AC9 (P0.14)
P0.19: U1.P$AC15 (P0.19)
P0.20: U1.P$AD16 (P0.20)
P0.21: U1.P$AC17 (P0.21)
P0.22: U1.P$AD18 (P0.22)
P0.23: U1.P$AC19 (P0.23)
P0.24: U1.P$AD20 (P0.24)
P0.25: U1.P$AC21 (P0.25)
P0.26: U1.P$G1 (P0.26)
P0.27: U1.P$H2 (P0.27)
P0.28: U1.P$B11 (P0.28/AIN4)
P0.29: U1.P$A10 (P0.29/AIN5)
P0.30: U1.P$B9 (P0.30/AIN6)
P0.31: U1.P$A8 (P0.31/AIN7)
P1.01/1.6C: Q1.1 (G), R_PWR_EPD.1
P1.01/2.4B: U1.P$Y23 (P1.01)
P1.02/1.6C: C29.2, R7.1, SW_DN.2
P1.02/2.8C: U1.P$W24 (P1.02)
P1.03: U1.P$V23 (P1.03)
P1.04: U1.P$U24 (P1.04)
P1.05: U1.P$T23 (P1.05)
P1.06: U1.P$R24 (P1.06)
P1.07: U1.P$P23 (P1.07)
P1.09: U1.P$R1 (P1.09)
P1.10: U1.P$A20 (P1.10)
P1.11: U1.P$B19 (P1.11)
P1.12: U1.P$B17 (P1.12)
P1.13: U1.P$A16 (P1.13)
P1.14: U1.P$B15 (P1.14)
P1.15: U1.P$A14 (P1.15)
PMIC_INT: IC1.A1 (!INT), U1.P$T2 (P0.11)
PREVGH: EPD_C9.2, J1.21
PREVGL: D2.2 (A), EPD_C11.2, J1.23
RESE: J1.3, Q3.2 (S), R1_EP_DR.2
RESET: J2.6, TP_RESET.TP, U1.P$AC13 (P0.18/RESET)
SCK/1.5B: J1.13
SCK/2.2D: U1.P$A12 (P0.02/AIN0)
SCL/1.4C: IC2.C1 (SCL), U2.7 (SCL)
SCL/2.4C: IC1.B1 (SCL), IC3.12 (SCX), R4.2, R17.2, TP_SCL.TP, U1.P$M2 (P0.07)
SDA/1.4C: IC2.B2 (SDA), U2.8 (SDA)
SDA/2.4C: IC1.C1 (SDA), IC3.2 (SDX), R2.2, R18.2, TP_SDA.TP, U1.P$L1 (P0.06)
SWDCLK: J2.4, TP_SWDCLK.TP, U1.P$AA24 (SWDCLK)
SWDIO: J2.2, TP_SWDIO.TP, U1.P$AC24 (SWDIO)
SWO: TP_SW0.TP, U1.P$AD22 (P1.00)
VBAT/1.2A: C27.2, TP_VBAT.TP, U2.2 (CELL), U2.3 (VDD)
VBAT/2.5C: C37.2, IC1.C2 (BAT)
VBUS/1.5D: C42.1, C43.1, D3.5 (VBUS), J4.A4_B9 (VBUS), J4.A9_B4 (VBUS)
VBUS/2.6D: C21.1, C38.2, IC1.A2 (IN), U1.P$AD2 (VBUS)
VREG: C23.2, C24.2, C39.1, IC1.B2 (SYS), IC9.A1 (EN), IC9.A2 (VIN_1), IC9.A3 (VIN_2), TP_VREG.TP

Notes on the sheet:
LiPo Charger
DC/DC
IMU
SWD
DEC1
P0.00/XL1
P0.00/XL2
DEC3
DEC4_6
Haptic Driver
Buttons
USB C Connector & ESD Protection
E-Paper Display Connector
Fuel Gauge
E-Paper Drive Circuit
DMG2305UX-7

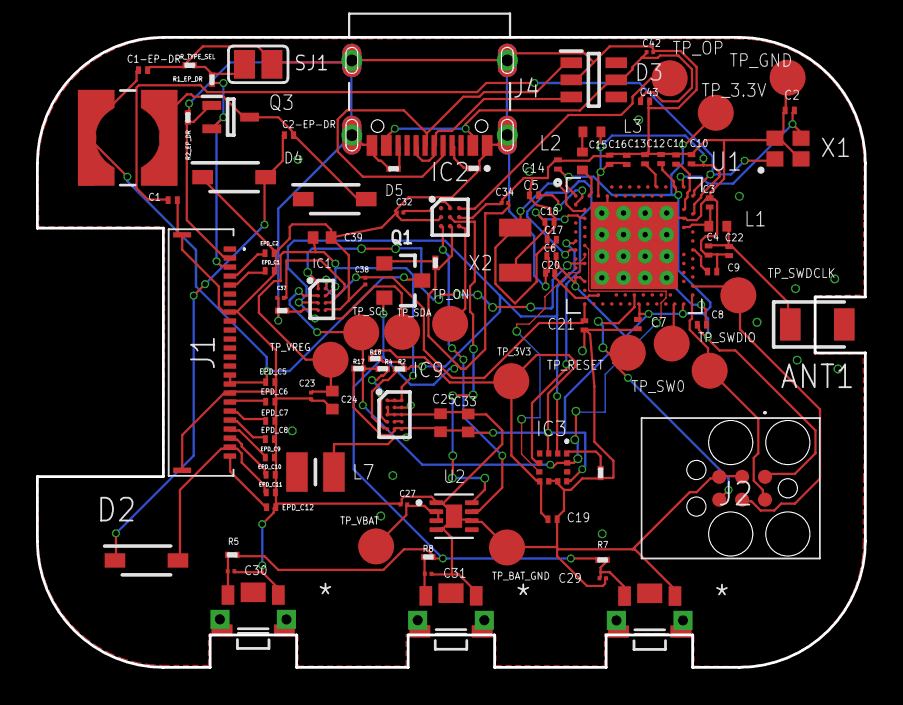
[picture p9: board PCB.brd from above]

Board: 2 copper layers, 46.0 x 35.0 mm, 105 parts (0 on the bottom side), 65 nets.

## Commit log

2026-04-19 Add files via upload
    Am adaugat varianta .pdf a fisierului schematic
2026-04-19 Add files via upload
    Am adaugat label-urile pieselor care nu aveau deja, astfel incat sa am silkscreen-ul complet.
    [PCB.brd]

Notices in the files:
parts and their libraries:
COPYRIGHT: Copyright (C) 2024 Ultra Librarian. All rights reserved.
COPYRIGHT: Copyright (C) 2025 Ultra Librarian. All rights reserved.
